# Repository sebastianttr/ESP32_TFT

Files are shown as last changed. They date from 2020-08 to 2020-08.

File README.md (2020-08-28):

# ESP32 2.4 inch TFT display driver
A ESP32 TFT board with USB Type C and additional headers for adding sensors.

For any questions make, sure to contact me. You can also DM me at @wired_less_maker
.

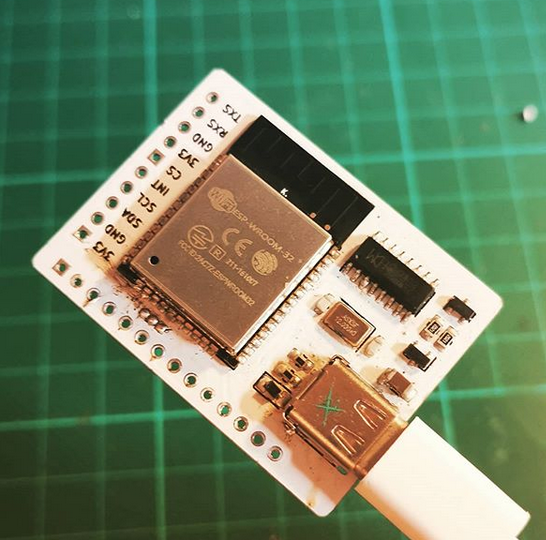
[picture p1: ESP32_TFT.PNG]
Test Image 2

# Parts List

This project requires several components: 

* ESP32 WROOM module
  * Preferably a ESP32U or a ESP32S, because of the ability to add an external antenna for better wireless performance
  Test Image 4
* USB Type C Receptable
  * Make sure you select the correct receptable, this is the footprint
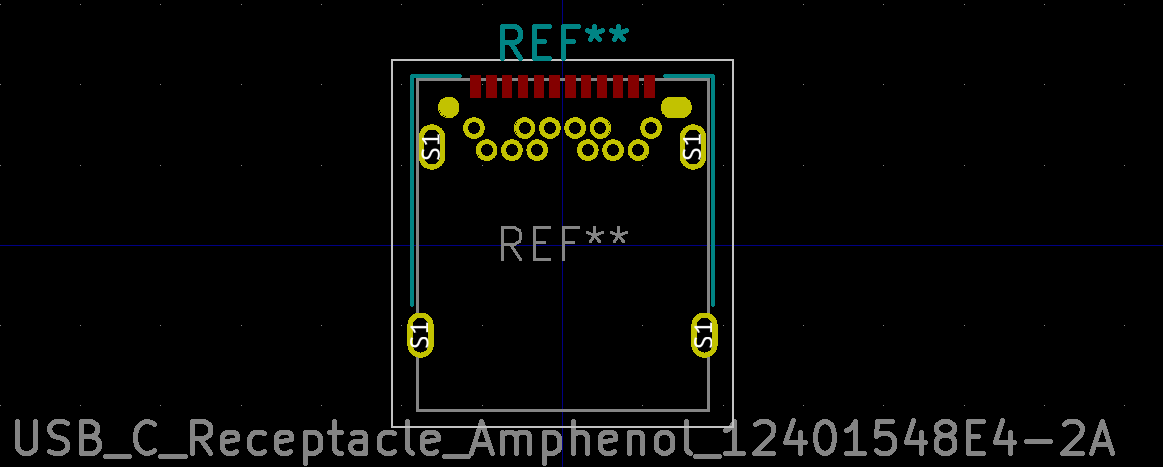
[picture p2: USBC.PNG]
USBC
  

* CH340 USB to TTL Converter IC
* LD1117 3V3 Regulator IC
* [OPTIONAL] RFM95 for LoRaWAN
   * If you decide on using LoRaWAN, make sure to also get a U.FL antenna connector 
* 2 SMD Buttons (6 mm X 3.9 mm)
* Passive components
   * 4x 10kOhm 0805 Resistor
   * 2x 5.1kOhm 0805 Resistor 
   * 2x 12kOhm 0805 Resistor
   * 1x Schottky Diode 1206 (the choice is yours)
   * 2x 100nF 0805 Capacitor
   * 1x 10uF 1206 Capacitor
   * 2x 22pF 0603 Capacitor 
   * 1x 12Mhz SMD Crystal 5.0 mm x 3.2 mm
     
     * You will need this configuration. Make sure to look into the datasheet 
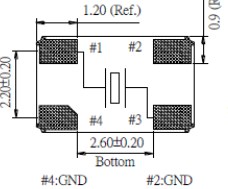
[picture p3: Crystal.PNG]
Crystal
       
   
   * 2x SOT-23-3 BJT Tranistor of either types: MMBT1000 or MMBT2222
     * S8050 is also OK
* LED
  * For LED, you can use whatever you like.
  * The LED Pin outputs 3.3V from the ESP32, in case you use a LED with a forward voltage lower than ~ 3.3V, you can calculate and add your own resistor at R10
  
# Before usage
  * Before using the device with the TFT touchscreen, make sure to jump these 2 pins above the touchscreen connector: 
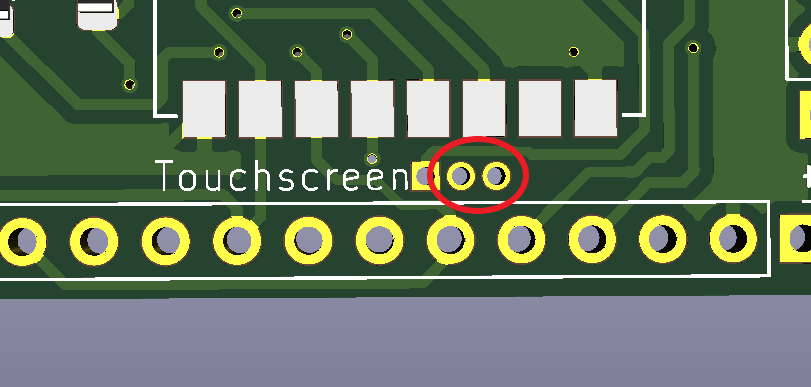
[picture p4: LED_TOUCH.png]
LED_TOUCH
  
  
  These pins exist to set the brightness of the backlight. In this case, we connect the LED- pin from the touchscreen with 3.3V.

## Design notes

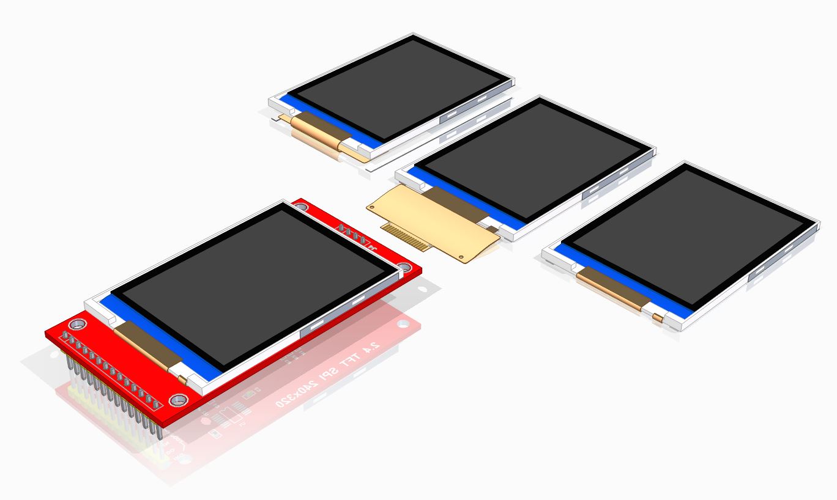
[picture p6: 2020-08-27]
Symbole_Footprints_3DModels/2.4 TFT.JPG

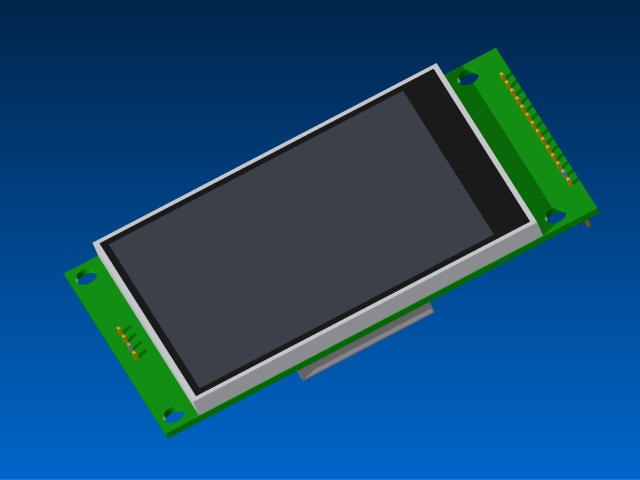
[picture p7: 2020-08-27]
Symbole_Footprints_3DModels/Renderings/ili9341_28.png

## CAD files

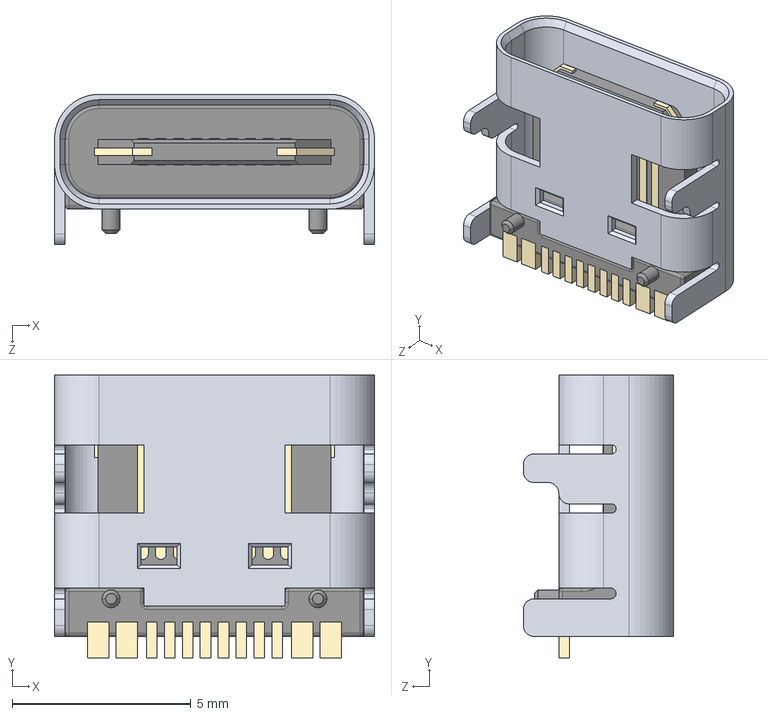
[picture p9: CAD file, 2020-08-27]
Symbole_Footprints_3DModels/USB Type C Port (SMD Type).STEP
8.94 x 7.90 x 4.20 mm

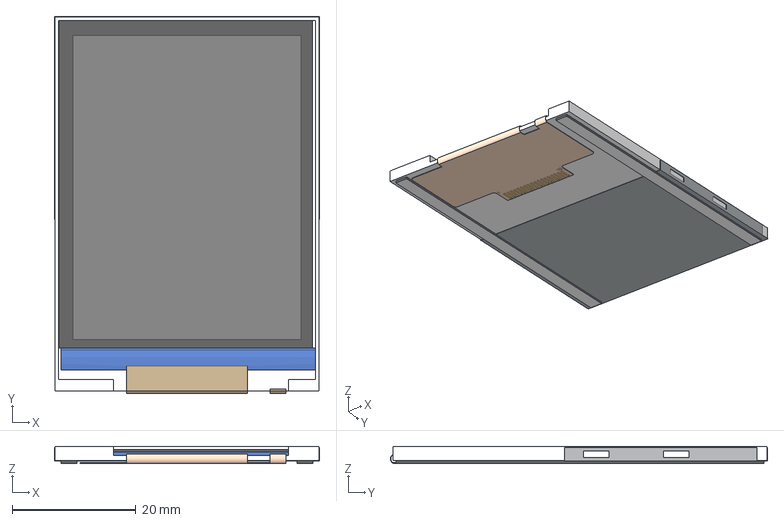
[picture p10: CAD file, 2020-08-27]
Symbole_Footprints_3DModels/2.4in TFT(Without Glass)- Tucked Cable.stp
42.7 x 60.8 x 2.74 mm

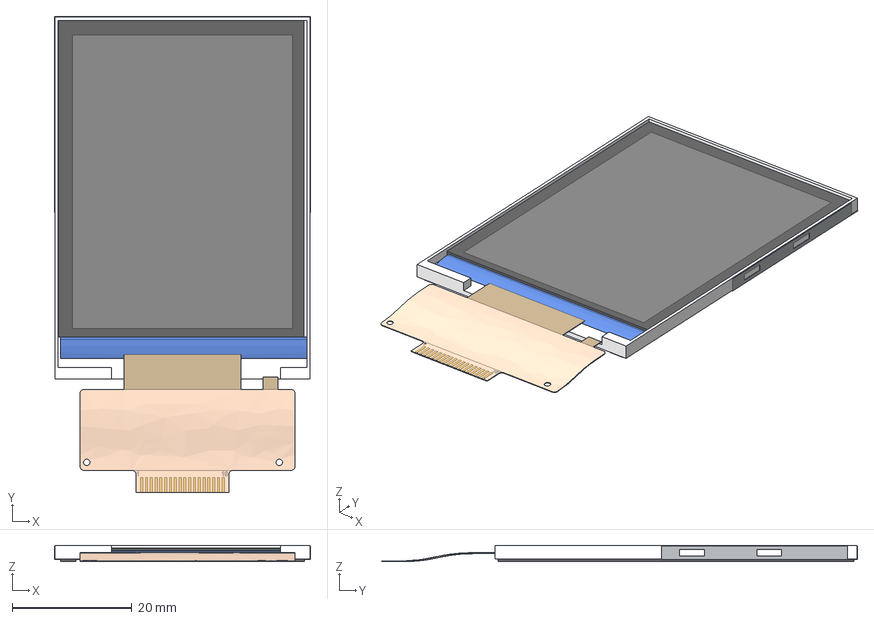
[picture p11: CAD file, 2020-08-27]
Symbole_Footprints_3DModels/2.4in TFT(Without Glass)- Flat Mount.stp
42.7 x 79.4 x 2.74 mm

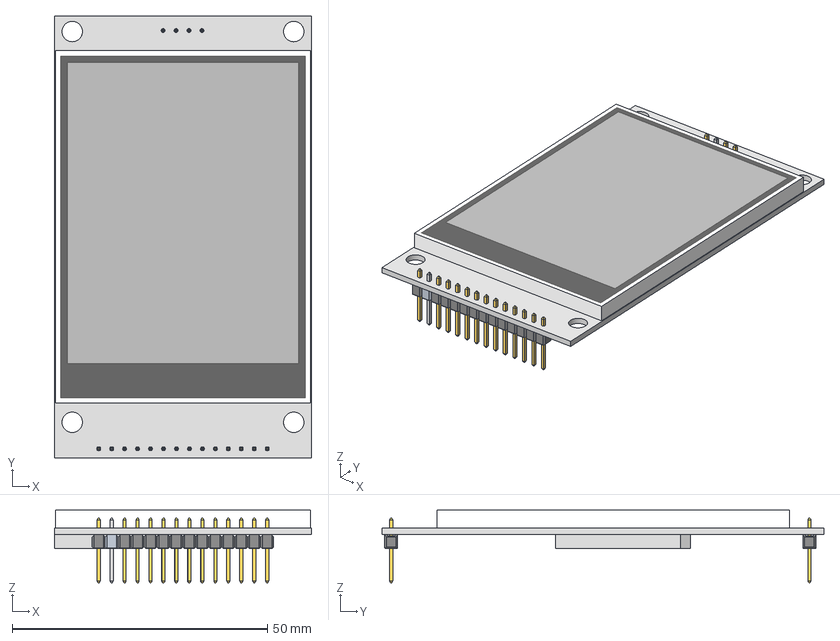
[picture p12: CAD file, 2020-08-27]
Symbole_Footprints_3DModels/ILI9341_28.stp
50.4 x 86.6 x 14.2 mm
ILI9341_28_layer
SDcard
EDGE
EDGE_1
EDGE_2
EDGE_3
EDGE_4
EDGE_5
EDGE_6
=_[0_1_1_12]
=_[0_1_1_13]
=_[0_1_1_14]
=_[0_1_1_15]
=_[0_1_1_17]
=_[0_1_1_18]
=_[0_1_1_19]
=_[0_1_1_20]
EDGE_7
EDGE_8
EDGE_9
EDGE_10
EDGE_11
EDGE_12
EDGE_13
=_[0_1_1_12]_1
=_[0_1_1_13]_1
=_[0_1_1_14]_1
=_[0_1_1_15]_1
=_[0_1_1_16]
=_[0_1_1_17]_1
=_[0_1_1_18]_1
=_[0_1_1_19]_1
=_[0_1_1_20]_1
=_[0_1_1_21]
=_[0_1_1_22]
=_[0_1_1_23]
=_[0_1_1_24]
=_[0_1_1_25]
=_[0_1_1_27]
=_[0_1_1_28]
=_[0_1_1_29]
=_[0_1_1_30]
=_[0_1_1_31]
=_[0_1_1_32]
=_[0_1_1_33]
=_[0_1_1_34]
=_[0_1_1_35]
=_[0_1_1_36]
=_[0_1_1_37]
=_[0_1_1_38]
=_[0_1_1_39]
=_[0_1_1_40]

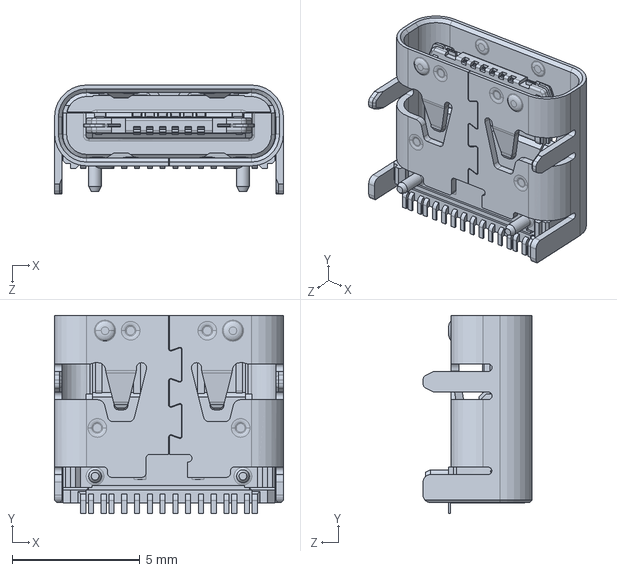
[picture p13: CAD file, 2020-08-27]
Symbole_Footprints_3DModels/USB - C.SLDPRT
8.95 x 7.75 x 4.26 mm

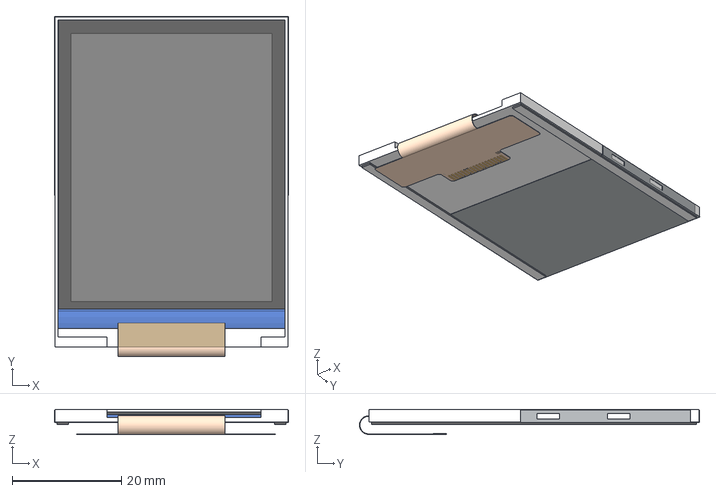
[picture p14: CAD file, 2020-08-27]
Symbole_Footprints_3DModels/2.4in TFT(Without Glass)- Reverse Mount.stp
42.7 x 62.1 x 4.60 mm

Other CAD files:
Symbole_Footprints_3DModels/USB Type C Port (SMD Type).SLDPRT

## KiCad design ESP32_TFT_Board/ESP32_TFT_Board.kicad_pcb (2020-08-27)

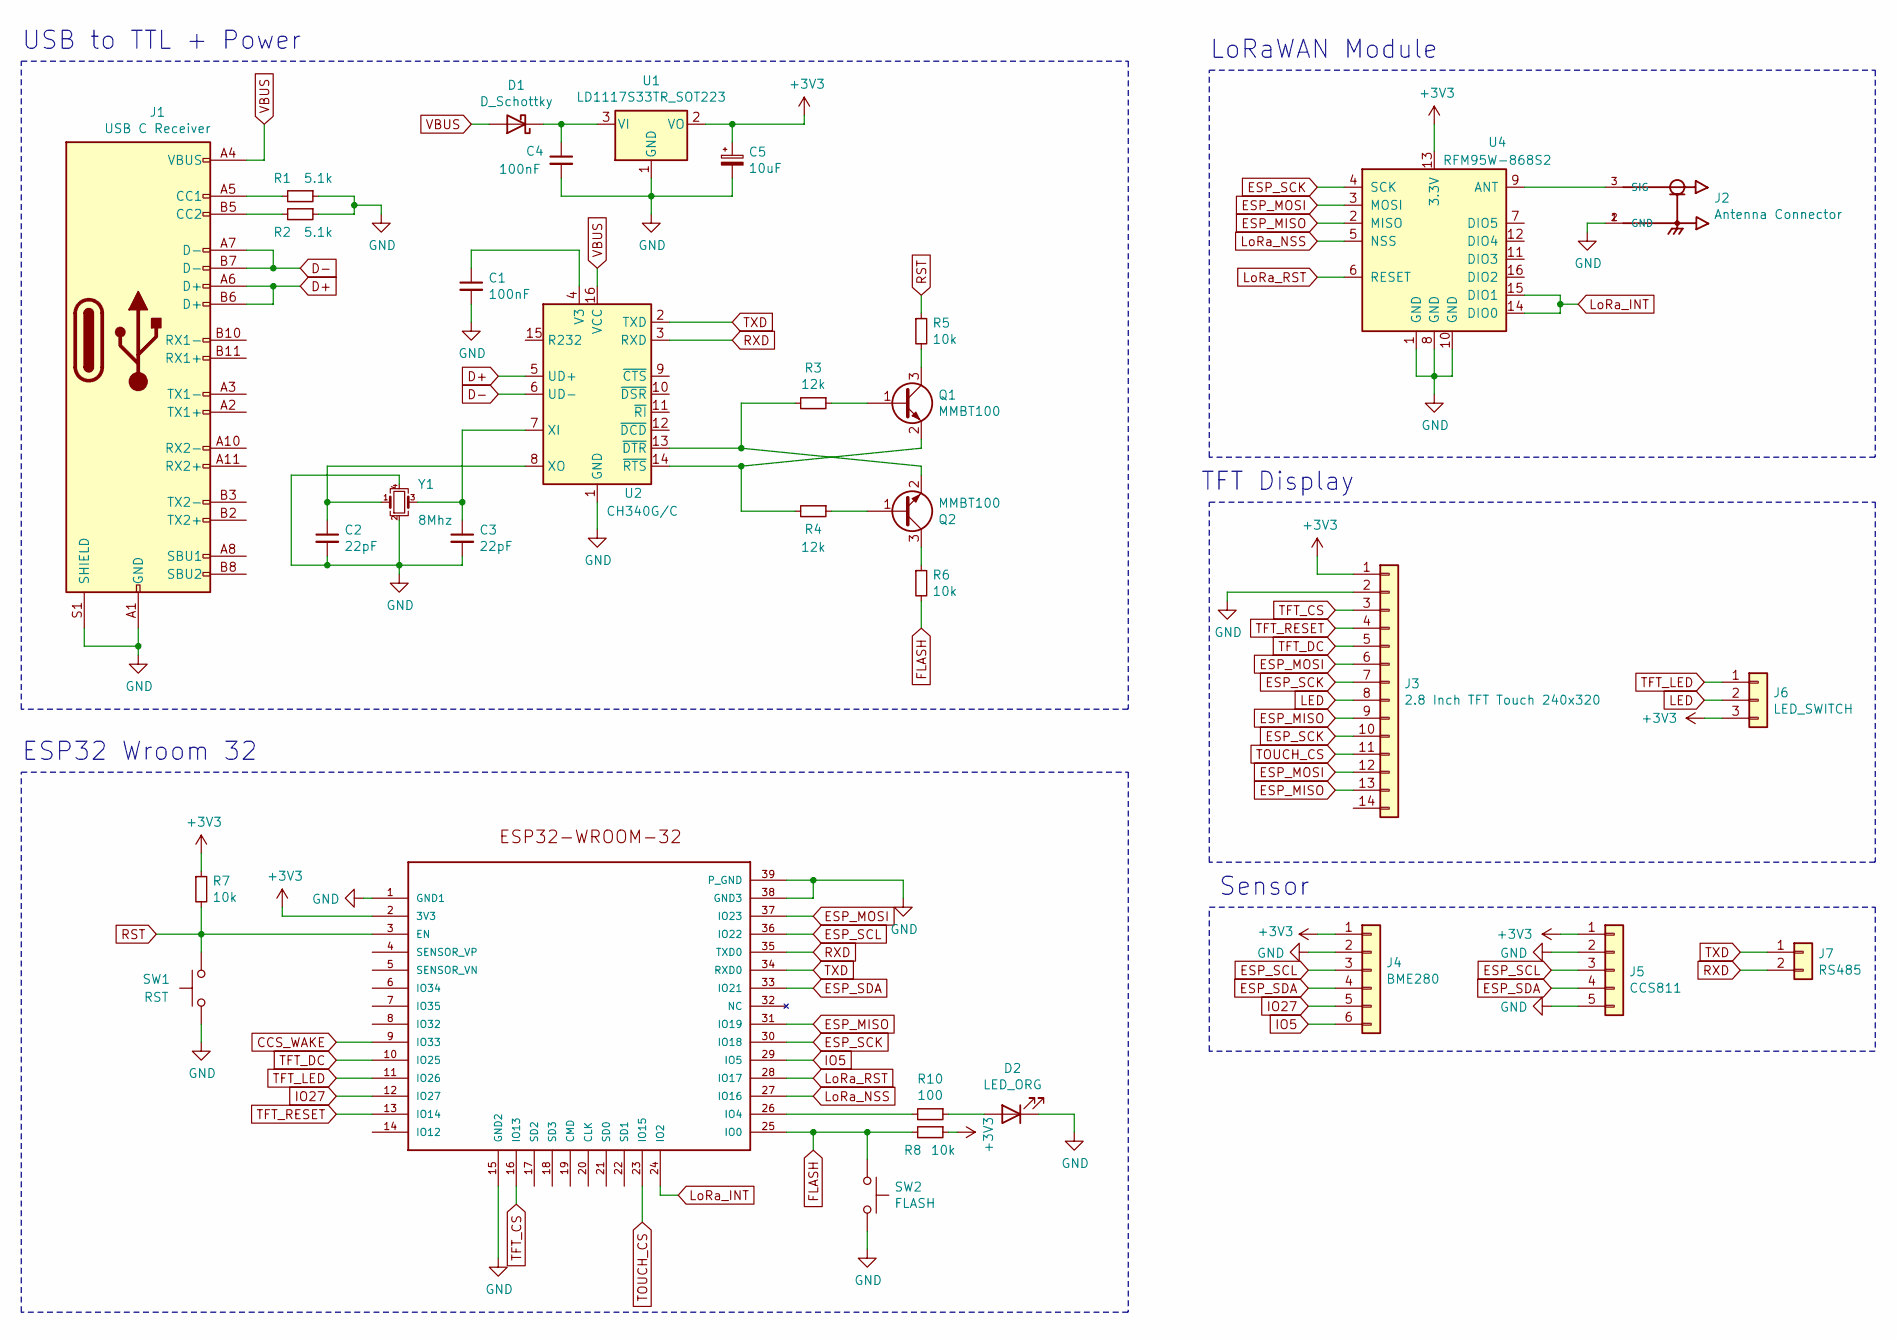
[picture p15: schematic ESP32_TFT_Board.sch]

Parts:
C1, C4: 100nF; C_0805_2012Metric_Pad1.15x1.40mm_HandSolder
C2, C3: 22pF; C_0603_1608Metric_Pad1.05x0.95mm_HandSolder
C5: 10uF; C_1206_3216Metric_Pad1.42x1.75mm_HandSolder
D1: D_Schottky; D_1206_3216Metric
D2: LED_ORG; LED_1206_3216Metric_Castellated
J1: USB C Receiver; USB_C_Receptacle_Amphenol_12401548E4-2A
J2: Antenna Connector; HRS_U.FL-R-SMT(01)
J3: 2.8 Inch TFT Touch 240x320; PinHeader_1x14_P2.54mm_Vertical
J4: BME280; PinHeader_1x06_P2.54mm_Vertical
J5: CCS811; PinHeader_1x05_P2.54mm_Vertical
J6: LED_SWITCH; PinHeader_1x03_P1.27mm_Vertical
J7: RS485; PinHeader_1x02_P1.27mm_Vertical
Q1, Q2: MMBT100; SOT-23
R1, R2: 5.1k; R_0805_2012Metric_Pad1.15x1.40mm_HandSolder
R3, R4: 12k; R_0805_2012Metric_Pad1.15x1.40mm_HandSolder
R5, R6, R7, R8: 10k; R_0805_2012Metric_Pad1.15x1.40mm_HandSolder
R10: 100; R_0805_2012Metric_Pad1.15x1.40mm_HandSolder
SW1: RST; SW_SPST_CK_RS282G05A3
SW2: FLASH; SW_SPST_CK_RS282G05A3
U1: LD1117S33TR_SOT223; SOT-223-3_TabPin2
U2: CH340G/C; SOIC-16_3.9x9.9mm_P1.27mm
U3: ESP32-WROOM-32
U4: RFM95W-868S2; Ai-Thinker-Ra-01-LoRa
Y1: 8Mhz; Crystal_SMD_5032-4Pin_5.0x3.2mm

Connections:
+3V3: C5.1, J3.1, J4.1, J5.1, J6.3, R7.1, R8.1, U1.2 (VO), U3.2 (3V3), U4.13 (3.3V)
CCS_WAKE: U3.9 (IO33)
D+: J1.A6 (D+), J1.B6 (D+), U2.5 (UD+)
D-: J1.A7 (D-), J1.B7 (D-), U2.6 (UD-)
ESP_MISO: J3.9, J3.13, U3.31 (IO19), U4.2 (MISO)
ESP_MOSI: J3.6, J3.12, U3.37 (IO23), U4.3 (MOSI)
ESP_SCK: J3.7, J3.10, U3.30 (IO18), U4.4 (SCK)
ESP_SCL: J4.3, J5.3, U3.36 (IO22)
ESP_SDA: J4.4, J5.4, U3.33 (IO21)
FLASH: R6.2, R8.2, SW2.1, U3.25 (IO0)
GND: C1.2, C2.2, C3.2, C4.2, C5.2, D2.1 (K), J1.A1 (GND), J1.A12 (GND), J1.B1 (GND), J1.B12 (GND), J1.S1 (SHIELD), J2.1 (GND), J2.2 (GND), J3.2, J4.2, J5.2, J5.5, R1.1, R2.1, SW1.1, SW2.2, U1.1 (GND), U2.1 (GND), U3.1 (GND1), U3.15 (GND2), U3.38 (GND3), U3.39 (P_GND), U4.1 (GND), U4.8 (GND), U4.10 (GND), Y1.2, Y1.4
IO5: J4.6, U3.29 (IO5)
IO27: J4.5, U3.12 (IO27)
LED: J3.8, J6.2
LoRa_INT: U3.24 (IO2), U4.14 (DIO0), U4.15 (DIO1)
LoRa_NSS: U3.27 (IO16), U4.5 (NSS)
LoRa_RST: U3.28 (IO17), U4.6 (RESET)
unnamed: C1.1, U2.4 (V3)
unnamed: C2.1, U2.8 (XO), Y1.1
unnamed: C3.1, U2.7 (XI), Y1.3
unnamed: C4.1, D1.1 (K), U1.3 (VI)
unnamed: D2.2 (A), R10.1
unnamed: J1.A5 (CC1), R1.2
unnamed: J1.B5 (CC2), R2.2
unnamed: J2.3 (SIG), U4.9 (ANT)
unnamed: Q1.1 (B), R3.1
unnamed: Q1.2 (E), R4.2, U2.14 (~RTS)
unnamed: Q1.3 (C), R5.2
unnamed: Q2.1 (B), R4.1
unnamed: Q2.2 (E), R3.2, U2.13 (~DTR)
unnamed: Q2.3 (C), R6.1
unnamed: R10.2, U3.26 (IO4)
RST: R5.1, R7.2, SW1.2, U3.3 (EN)
RXD: J7.2, U2.3 (RXD), U3.35 (TXD0)
TFT_CS: J3.3, U3.16 (IO13)
TFT_DC: J3.5, U3.10 (IO25)
TFT_LED: J6.1, U3.11 (IO26)
TFT_RESET: J3.4, U3.13 (IO14)
TOUCH_CS: J3.11, U3.23 (IO15)
TXD: J7.1, U2.2 (TXD), U3.34 (RXD0)
VBUS: D1.2 (A), J1.A4 (VBUS), J1.A9 (VBUS), J1.B4 (VBUS), J1.B9 (VBUS), U2.16 (VCC)

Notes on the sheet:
USB to TTL + Power
ESP32 Wroom 32
LoRaWAN Module
TFT Display
Sensor

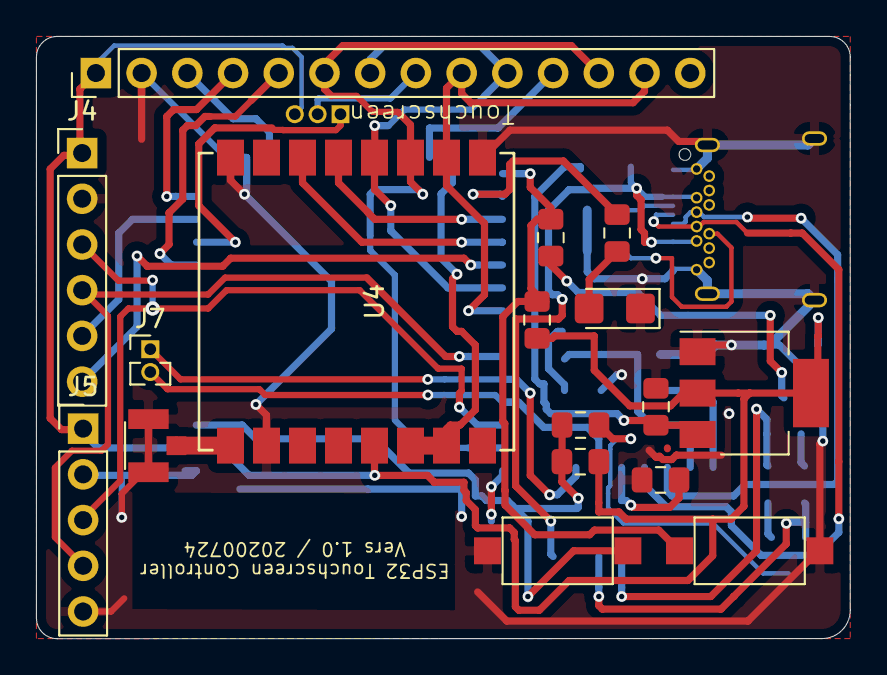
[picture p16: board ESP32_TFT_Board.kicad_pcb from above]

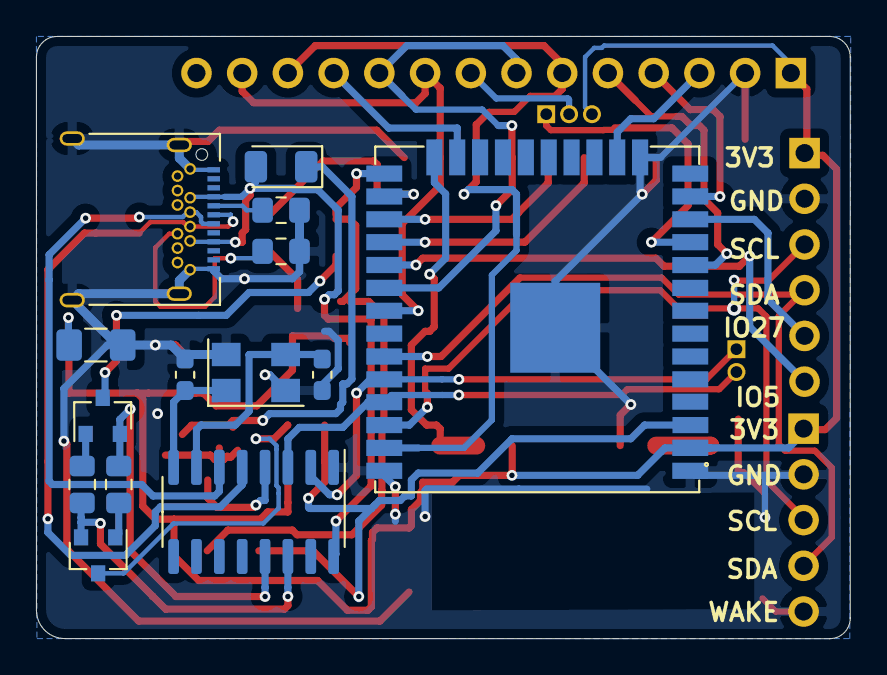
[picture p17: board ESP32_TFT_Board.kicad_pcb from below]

Board: 2 copper layers, 45.2 x 33.5 mm, 32 parts (14 on the bottom side), 40 nets.
